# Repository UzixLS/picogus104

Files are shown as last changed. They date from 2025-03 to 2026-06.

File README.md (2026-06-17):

## PicoGUS/104
Gravis Ultrasound compatible sound card for IBM PC.

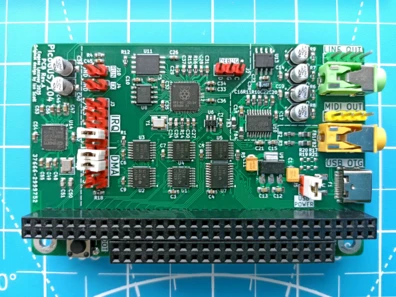
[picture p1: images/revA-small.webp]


This is variant of [PicoGUS](https://picog.us/) v2.0 project by [Ian Scott](https://ianscott.org/) adapted for PC/104 bus. This variant also integrates SAM2695 MIDI synthesizer on board.

For details and firmware please follow this link: https://github.com/polpo/picogus

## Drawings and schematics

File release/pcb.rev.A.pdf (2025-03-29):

220 | C19
IRQ | 42 GND 45 | VD³³ ⁴⁶ XDIV | 47 GND 48 VCM | 5 VA³³

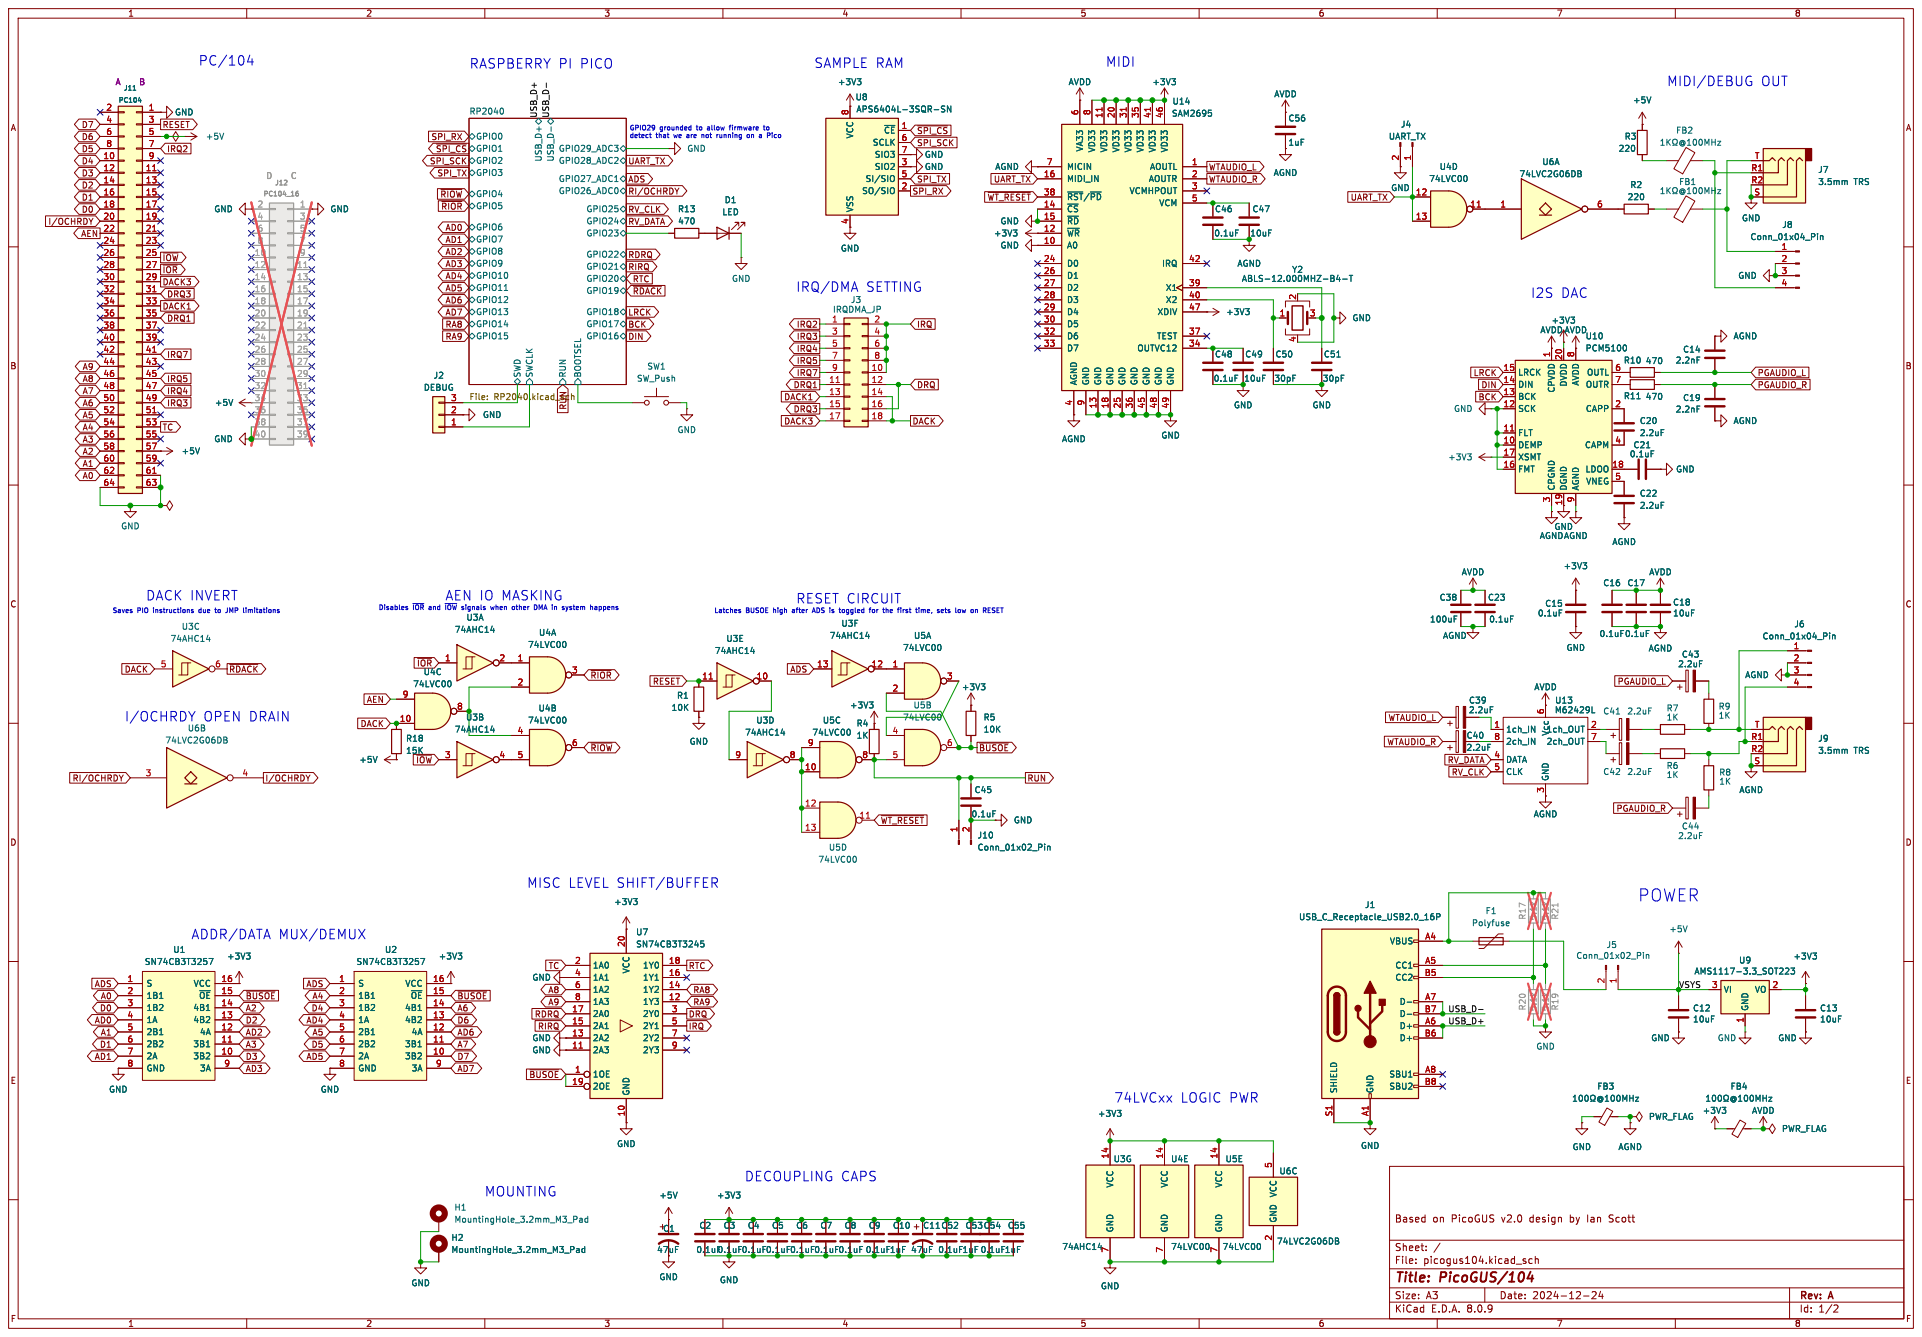
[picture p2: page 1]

4 SI/SIO 5 SCLK 6 SIO3 7 VCC
~{CE}1 SO/SIO 2 SIO2 3 VSS

1 DEMP 10 FLT 11 SCK 12 BCK 13 DIN 14

3 CAPM 4 VNEG 5 OUTL 6 OUTR 7 AVDD

MISC LEVEL SHIFT/BUFFER

ADDR/DATA MUX/DEMUX

100n C31

# 100n Raspberry Pi

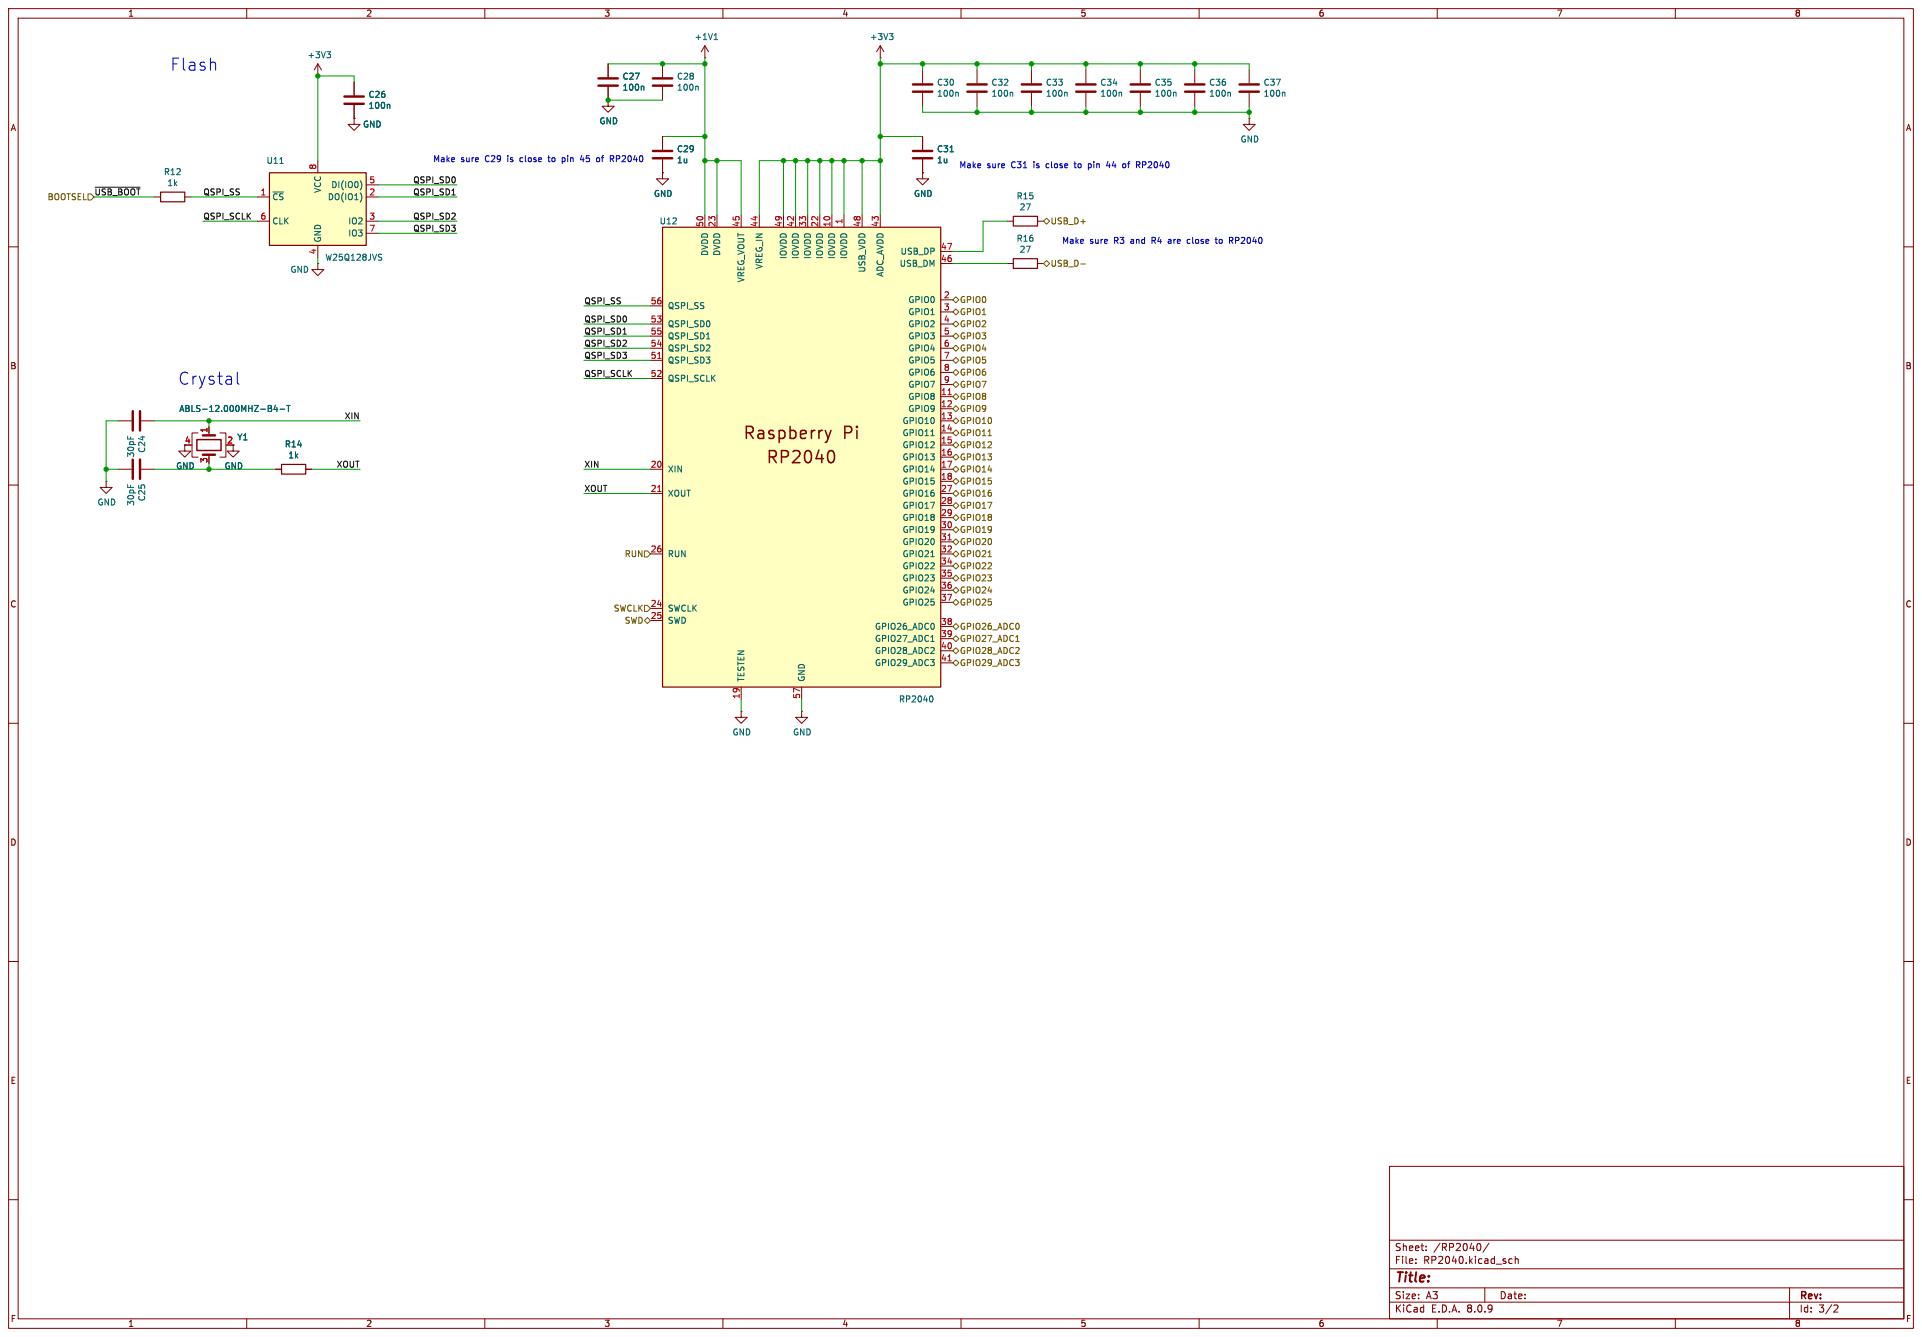
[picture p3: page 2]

1 IOVDD 10 GPIO8 11 GPIO9 12 GPIO10 13 GPIO11 14 GPIO12 15 GPIO13 16 GPIO14 17 GPIO15 18 TESTEN 19 GPIO0 2 XIN 20 XOUT 21 IOVDD 22 DVDD 23 SWCLK 24 SWD 25 RUN 26 GPIO16 27 GPIO17 28 GPIO18 29 GPIO1 3 GPIO19 30 GPIO20 31 GPIO21 32 IOVDD 33 GPIO22 34 GPIO23 35 GPIO24 36 GPIO25 37 GPIO26_ADC0 38 GPIO27_ADC1 39 GPIO2 4 GPIO28_ADC2 40 GPIO29_ADC3 41 IOVDD 42 ADC_AVDD 43 VREG_IN 44 VREG_VOUT 45 USB_DM 46 USB_DP 47 USB_VDD 48 IOVDD 49 GPIO3 5 DVDD 50 QSPI_SD3 51 QSPI_SCLK 52 QSPI_SD0 53 QSPI_SD2 54 QSPI_SD1 55 QSPI_SS 56 GND 57 GPIO4 6 GPIO5 7 GPIO6 8 GPIO7 9 U12 RP2040

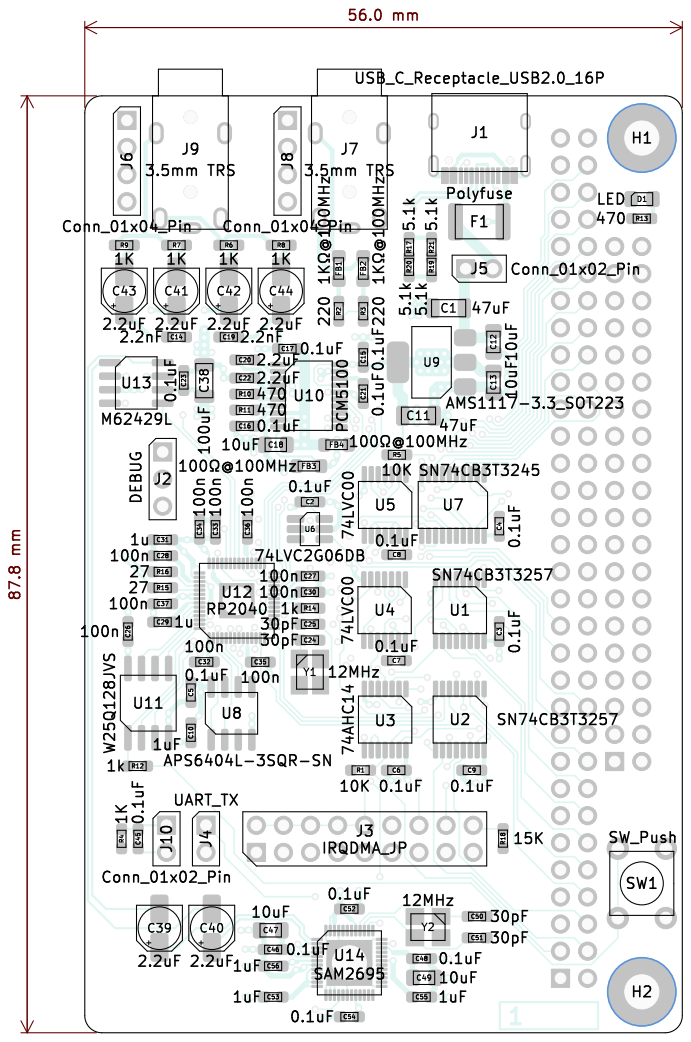
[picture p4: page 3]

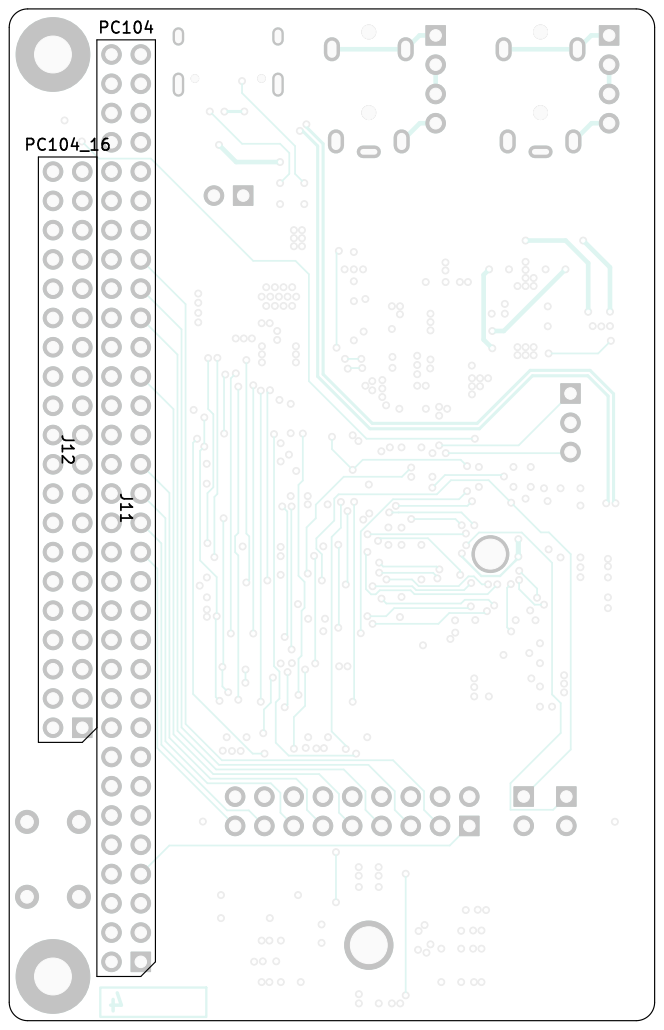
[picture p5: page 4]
D Date: 2024-12-24 KiCad; E.D.A. 8.0.9 Size: A4; Rev: A; File: picogus104.kicad_pcb Sheet: Eugene; Lozovoy Thickness: 1.6mm; Layers: 4 Dimensions:; Min; hole: 0.3mm; Min clearance:; Min track:

Min annular ring: 0.15mm

Id: 1/1 Title: PicoGUS/104

# Bill Of Materials

References | | | Value | Footprint | Qty
C1 C11 | 47uF | Capacitor_SMD:C_1206_3216Metric | 2
C2 C3 C4 C5 C6 C7 C8 C9 C15 C16 C17 C21 C23 C45 C46 C48 C52 C54 | 0.1uF | Capacitor_SMD:C_0603_1608Metric_Pad1.0 8x0.95mm_HandSolder | 18
C10 C53 C55 C56 | 1uF | Capacitor_SMD:C_0603_1608Metric_Pad1.0 8x0.95mm_HandSolder | 4
C12 C13 C18 C47 C49 | 10uF | Capacitor_SMD:C_0805_2012Metric_Pad1.1 8x1.45mm_HandSolder | 5
C14 C19 | 2.2nF | Capacitor_SMD:C_0603_1608Metric_Pad1.0 8x0.95mm_HandSolder | 2
C20 C22 | 2.2uF | Capacitor_SMD:C_0603_1608Metric_Pad1.0 8x0.95mm_HandSolder | 2
C38 | 100uF | Capacitor_SMD:C_1206_3216Metric | 1
C39 C40 C41 C42 C43 C44 | 2.2uF | Capacitor_SMD:CP_Elec_4x5.4 | 6
C50 C51 C24 C25 | 30pF | Capacitor_SMD:C_0603_1608Metric_Pad1.0 8x0.95mm_HandSolder | 4
D1 | LED | LED_SMD:LED_0805_2012Metric_Pad1.15x 1.40mm_HandSolder | 1
F1 | Polyfuse | Fuse:Fuse_1812_4532Metric_Pad1.30x3.40 mm_HandSolder | 1
FB1 FB2 | 1KΩ@100MHz | Inductor_SMD:L_0805_2012Metric_Pad1.05 x1.20mm_HandSolder | 2
FB3 FB4 | 100Ω@100MHz | Inductor_SMD:L_0805_2012Metric_Pad1.05 x1.20mm_HandSolder | 2
J1 | USB_C_Receptacle_USB2.0_16P | Connector_USB:USB_C_Receptacle_HRO_ TYPE-C-31-M-12 | 1
J3 | IRQDMA_JP | Connector_PinHeader_2.54mm:PinHeader_2 x09_P2.54mm_Vertical | 1
J6 J8 | Conn_01x04_Pin | Connector_PinHeader_2.54mm:PinHeader_1 x04_P2.54mm_Vertical | 2
J7 J9 | 3.5mm TRS | my:PJ-322 | 2
J11 | PC104 | Connector_PinHeader_2.54mm:PinHeader_2 x32_P2.54mm_Vertical | 1
R1 R5 | 10K | Resistor_SMD:R_0603_1608Metric_Pad0.98 x0.95mm_HandSolder | 2
R2 R3 | 220 | Resistor_SMD:R_0603_1608Metric_Pad0.98 x0.95mm_HandSolder | 2
R4 R6 R7 R8 R9 | 1K | Resistor_SMD:R_0603_1608Metric_Pad0.98 x0.95mm_HandSolder | 5
R10 R11 R13 | 470 | Resistor_SMD:R_0603_1608Metric_Pad0.98 x0.95mm_HandSolder | 3
R18 | 15K | Resistor_SMD:R_0603_1608Metric_Pad0.98 x0.95mm_HandSolder | 1
SW1 | SW_Push | Button_Switch_THT:SW_PUSH_6mm | 1
U1 U2 | SN74CB3T3257 | Package_SO:TSSOP-16_4.4x5mm_P0.65m m | 2
U3 | 74AHC14 | Package_SO:TSSOP-14_4.4x5mm_P0.65m m | 1

# picogus104 rev.A BOM page 1/2

U4 U5 | 74LVC00 | Package_SO:TSSOP-14_4.4x5mm_P0.65m m | 2
U6 | 74LVC2G06DB | Package_TO_SOT_SMD:SOT-23-6_Handsol dering | 1
U7 | SN74CB3T3245 | Package_SO:TSSOP-20_4.4x6.5mm_P0.65 mm | 1
U8 | APS6404L-3SQR-SN | Package_SO:SOIC-8_3.9x4.9mm_P1.27mm | 1
U9 | AMS1117-3.3_SOT223 | Package_TO_SOT_SMD:SOT-223-3_TabPin 2 | 1
U10 | PCM5100 | Package_SO:TSSOP-20_4.4x6.5mm_P0.65 mm | 1
U13 | M62429L | Package_SO:SOIC-8_3.9x4.9mm_P1.27mm | 1
U14 | SAM2695 | my:QFN-48-1EP_6x6mm_P0.4mm_EP4.2x4. 2mm | 1
Y2 Y1 | ABLS-12.000MHZ-B4-T | my:Crystal_SMD_3225-4Pin_3.2x2.5mm_Ha ndSoldering | 2
C26 C27 C28 C30 C32 C33 C34 C35 C36 C37 | 100n | Capacitor_SMD:C_0603_1608Metric_Pad1.0 8x0.95mm_HandSolder | 10
C29 C31 | 1u | Capacitor_SMD:C_0603_1608Metric_Pad1.0 8x0.95mm_HandSolder | 2
R12 R14 | 1k | Resistor_SMD:R_0603_1608Metric_Pad0.98 x0.95mm_HandSolder | 2
R15 R16 | 27 | Resistor_SMD:R_0603_1608Metric_Pad0.98 x0.95mm_HandSolder | 2
U11 | W25Q128JVS | my:SOIC-8_5.23x5.23mm_P1.27mm-LONG | 1
U12 | RP2040 | my:QFN-56-1EP_7x7mm_P0.4mm_EP3.2x3. 2mm | 1

# picogus104 rev.A BOM page 2/2

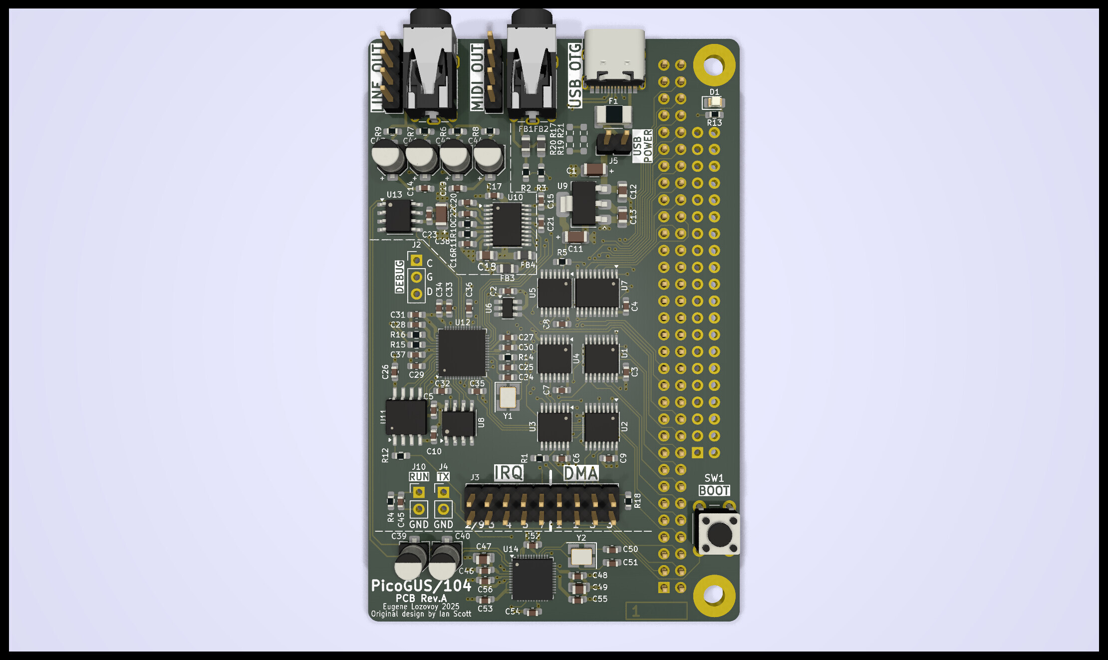
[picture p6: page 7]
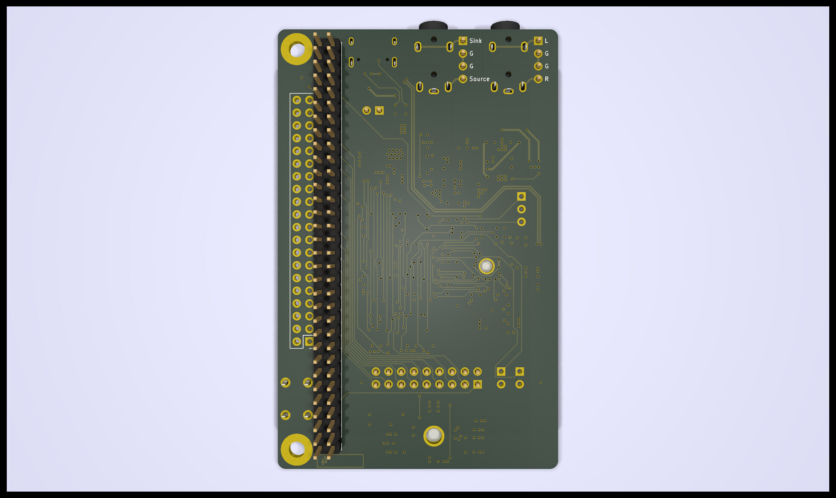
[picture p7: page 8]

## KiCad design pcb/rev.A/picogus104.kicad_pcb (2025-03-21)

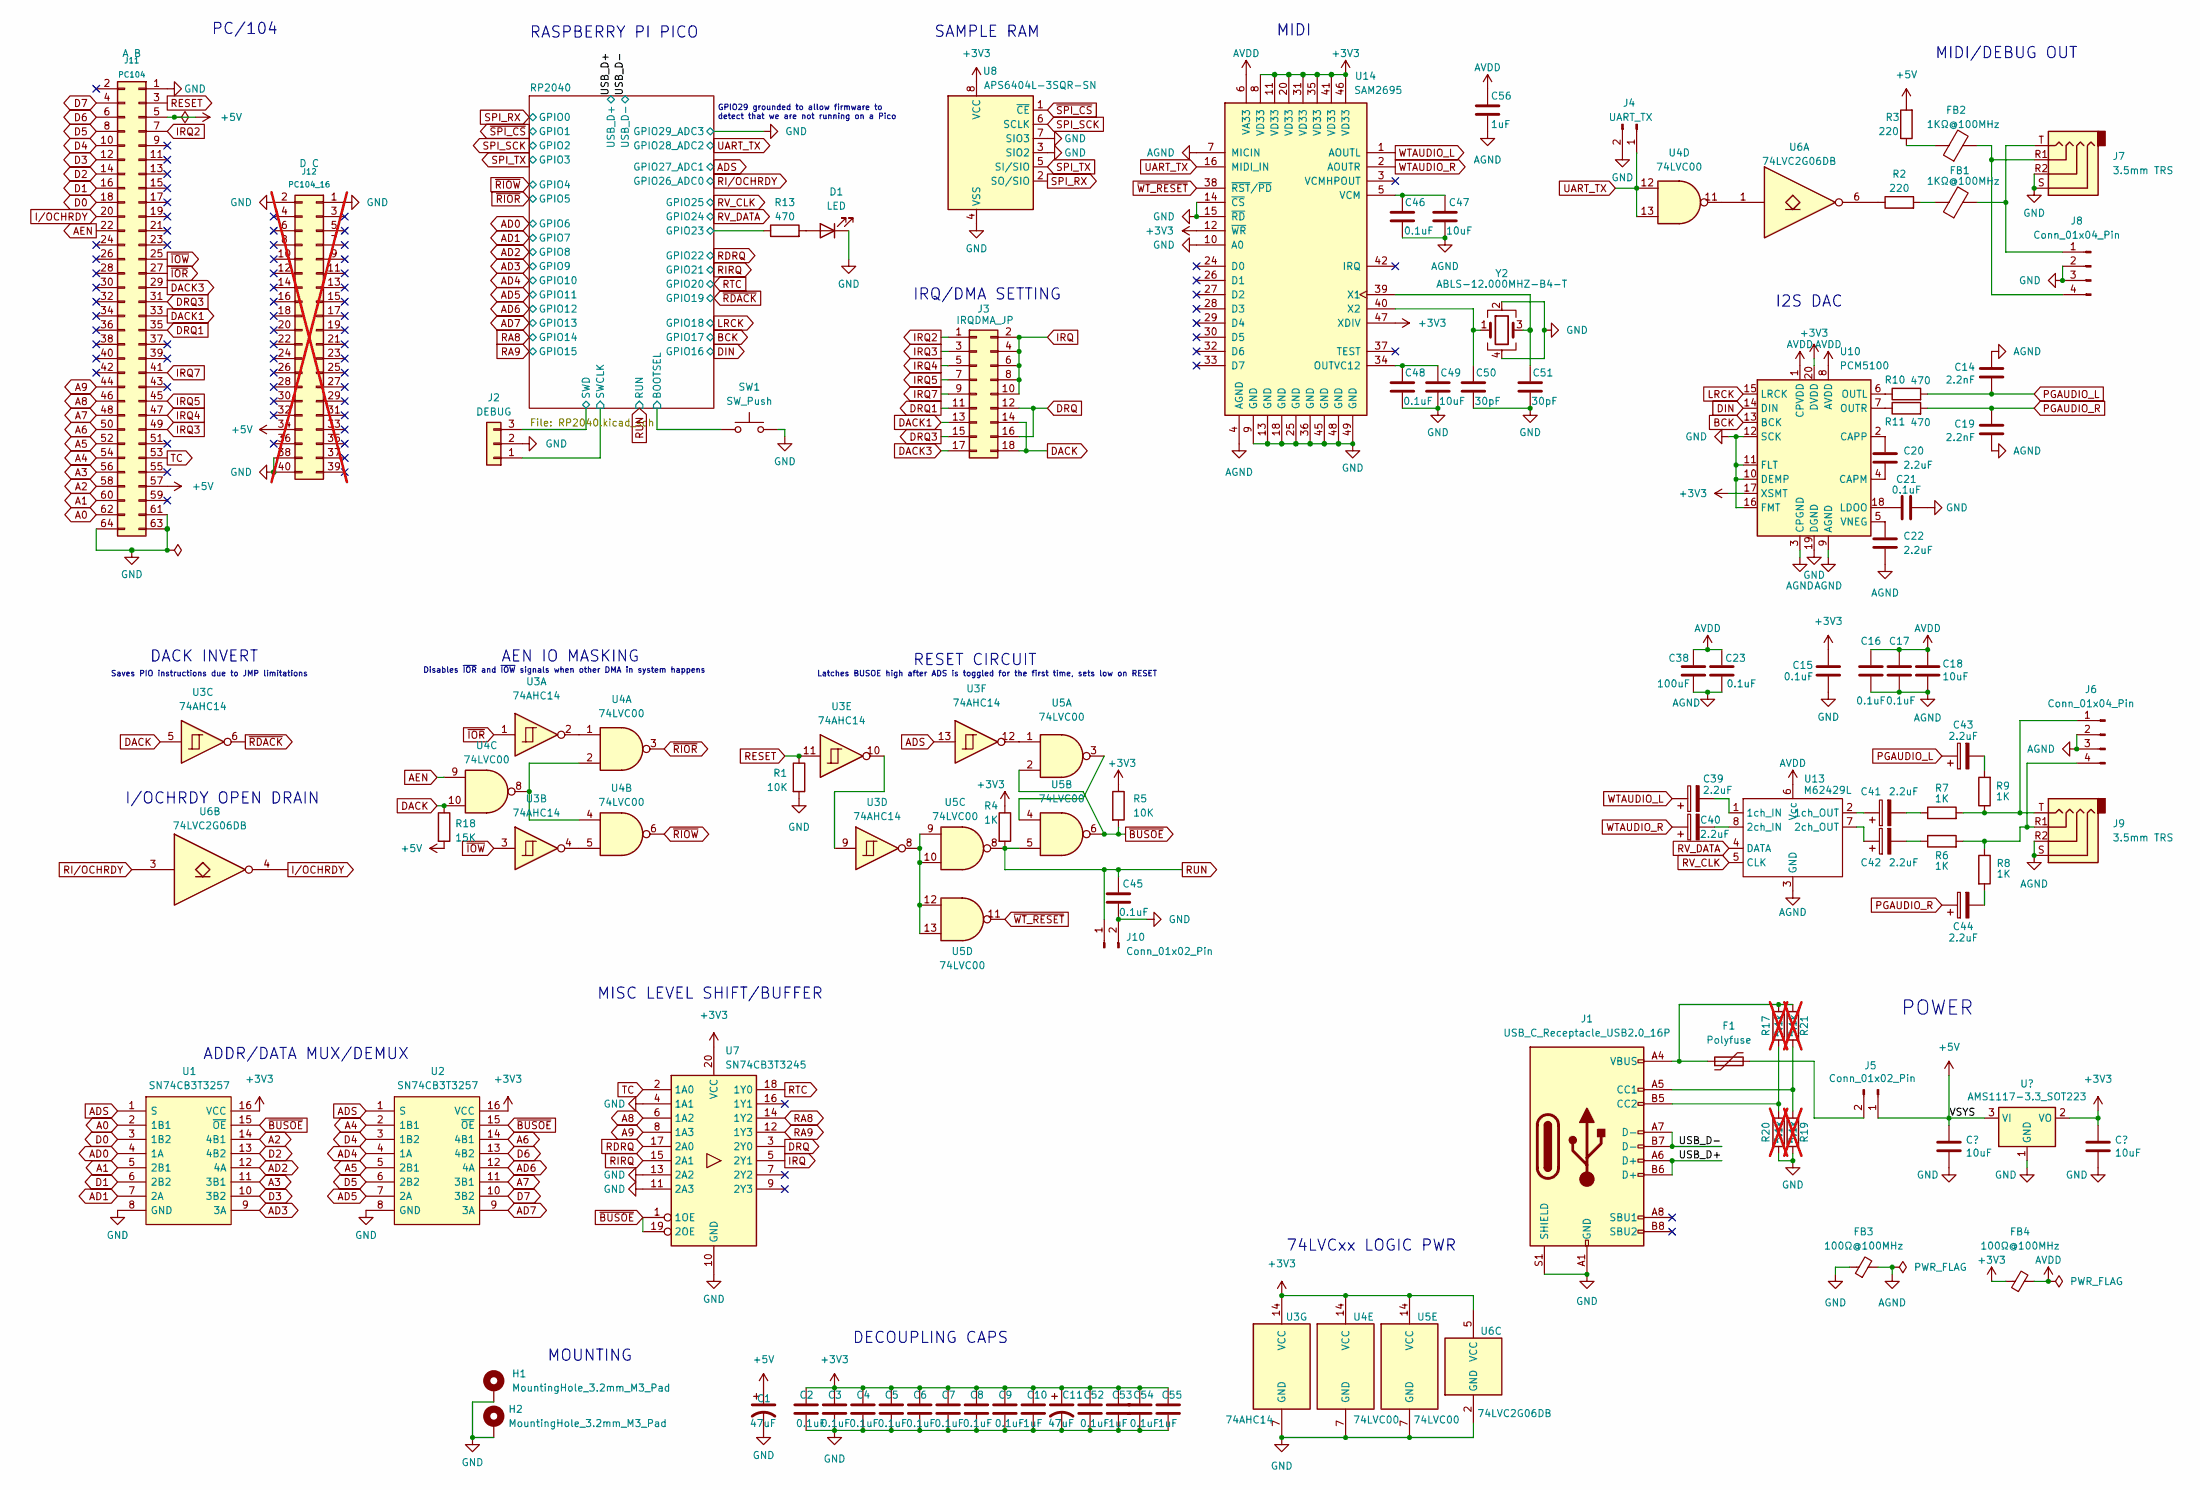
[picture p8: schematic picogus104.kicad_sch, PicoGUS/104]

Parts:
C1, C11: 47uF; C_1206_3216Metric
C2, C3, C4, C5, C6, C7, C8, C9, C15, C16, C17, C21, C23, C45, C46, C48, C52, C54: 0.1uF; C_0603_1608Metric_Pad1.08x0.95mm_HandSolder
C10, C53, C55, C56: 1uF; C_0603_1608Metric_Pad1.08x0.95mm_HandSolder
C12, C13, C18, C47, C49: 10uF; C_0805_2012Metric_Pad1.18x1.45mm_HandSolder
C14, C19: 2.2nF; C_0603_1608Metric_Pad1.08x0.95mm_HandSolder
C20, C22: 2.2uF; C_0603_1608Metric_Pad1.08x0.95mm_HandSolder
C38: 100uF; C_1206_3216Metric
C39, C40, C41, C42, C43, C44: 2.2uF; CP_Elec_4x5.4
C50, C51: 30pF; C_0603_1608Metric_Pad1.08x0.95mm_HandSolder
D1: LED; LED_0805_2012Metric_Pad1.15x1.40mm_HandSolder
F1: Polyfuse; Fuse_1812_4532Metric_Pad1.30x3.40mm_HandSolder
FB1, FB2: 1KΩ@100MHz; L_0805_2012Metric_Pad1.05x1.20mm_HandSolder
FB3, FB4: 100Ω@100MHz; L_0805_2012Metric_Pad1.05x1.20mm_HandSolder
H1, H2: MountingHole_3.2mm_M3_Pad
J1: USB_C_Receptacle_USB2.0_16P; USB_C_Receptacle_HRO_TYPE-C-31-M-12
J2: DEBUG; PinHeader_1x03_P2.54mm_Vertical
J3: IRQDMA_JP; PinHeader_2x09_P2.54mm_Vertical
J4: UART_TX; PinHeader_1x02_P2.54mm_Vertical
J5, J10: Conn_01x02_Pin; PinHeader_1x02_P2.54mm_Vertical
J6, J8: Conn_01x04_Pin; PinHeader_1x04_P2.54mm_Vertical
J7, J9: 3.5mm TRS; PJ-322
J11: PC104; PinHeader_2x32_P2.54mm_Vertical
J12: PC104_16; PinHeader_2x20_P2.54mm_Vertical; not fitted
R1, R5: 10K; R_0603_1608Metric_Pad0.98x0.95mm_HandSolder
R2, R3: 220; R_0603_1608Metric_Pad0.98x0.95mm_HandSolder
R4, R6, R7, R8, R9: 1K; R_0603_1608Metric_Pad0.98x0.95mm_HandSolder
R10, R11, R13: 470; R_0603_1608Metric_Pad0.98x0.95mm_HandSolder
R17, R19, R20, R21: 5.1k; R_0603_1608Metric_Pad0.98x0.95mm_HandSolder; not fitted
R18: 15K; R_0603_1608Metric_Pad0.98x0.95mm_HandSolder
SW1: SW_Push; SW_PUSH_6mm
U1, U2: SN74CB3T3257; TSSOP-16_4.4x5mm_P0.65mm; Manufacturer_Part_Number 74FST3257DR2G; Mouser Part Number 863-74FST3257DR2G
U3: 74AHC14; TSSOP-14_4.4x5mm_P0.65mm
U4, U5: 74LVC00; TSSOP-14_4.4x5mm_P0.65mm
U6: 74LVC2G06DB; SOT-23-6_Handsoldering
U7: SN74CB3T3245; TSSOP-20_4.4x6.5mm_P0.65mm
U8: APS6404L-3SQR-SN; SOIC-8_3.9x4.9mm_P1.27mm
U9: AMS1117-3.3_SOT223; SOT-223-3_TabPin2
U10: PCM5100; TSSOP-20_4.4x6.5mm_P0.65mm
U13: M62429L; SOIC-8_3.9x4.9mm_P1.27mm
U14: SAM2695; QFN-48-1EP_6x6mm_P0.4mm_EP4.2x4.2mm
Y2: ABLS-12.000MHZ-B4-T; Crystal_SMD_3225-4Pin_3.2x2.5mm_HandSoldering

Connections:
+3V3: C2.1, C3.1, C4.1, C5.1, C6.1, C7.1, C8.1, C9.1, C10.1, C11.1, C13.1, C15.2, C52.1, C53.1, C54.1, C55.1, FB4.1, R4.1, R5.1, U1.16 (VCC), U2.16 (VCC), U3.14 (VCC), U4.14 (VCC), U5.14 (VCC), U6.5 (VCC), U7.20 (VCC), U8.8 (VCC), U9.2 (VO), U10.17 (XSMT), U10.20 (DVDD), U14.8 (VD33), U14.11 (VD33), U14.12 (~WR), U14.20 (VD33), U14.31 (VD33), U14.35 (VD33), U14.41 (VD33), U14.46 (VD33), U14.47 (XDIV); also elsewhere on the board
+5V: C1.1, C12.1, J5.1, J11.5, J11.57, J12.34, R3.2, R18.2, U9.3 (VI)
/RP2040/GPIO23: R13.1; also elsewhere on the board
/RP2040/SWCLK: J2.1; also elsewhere on the board
/RP2040/SWD: J2.3; also elsewhere on the board
/RP2040/~USB_BOOT: SW1.2; also elsewhere on the board
/USB_D+: J1.A6 (D+), J1.B6 (D+); also elsewhere on the board
/USB_D-: J1.A7 (D-), J1.B7 (D-); also elsewhere on the board
A0: J11.62, U1.2 (1B1)
A1: J11.60, U1.5 (2B1)
A2: J11.58, U1.14 (4B1)
A3: J11.56, U1.11 (3B1)
A4: J11.54, U2.2 (1B1)
A5: J11.52, U2.5 (2B1)
A6: J11.50, U2.14 (4B1)
A7: J11.48, U2.11 (3B1)
A8: J11.46, U7.6 (1A2)
A9: J11.44, U7.8 (1A3)
AD0: U1.4 (1A); also elsewhere on the board
AD1: U1.7 (2A); also elsewhere on the board
AD2: U1.12 (4A); also elsewhere on the board
AD3: U1.9 (3A); also elsewhere on the board
AD4: U2.4 (1A); also elsewhere on the board
AD5: U2.7 (2A); also elsewhere on the board
AD6: U2.12 (4A); also elsewhere on the board
AD7: U2.9 (3A); also elsewhere on the board
ADS: U1.1 (S), U2.1 (S), U3.13; also elsewhere on the board
AEN: J11.22, U4.9
AGND: C14.1, C16.1, C17.1, C18.2, C19.1, C22.2, C23.2, C38.2, C46.1, C47.1, C56.2, FB3.2, J6.2, J6.3, J9.R2, J9.S, U10.3 (CPGND), U10.9 (AGND), U13.3 (GND), U14.4 (AGND), U14.7 (MICIN)
AVDD: C16.2, C17.2, C18.1, C23.1, C38.1, C56.1, FB4.2, U10.1 (CPVDD), U10.8 (AVDD), U13.6 (Vcc), U14.6 (VA33)
BCK: U10.13 (BCK); also elsewhere on the board
D0: J11.18, U1.3 (1B2)
D1: J11.16, U1.6 (2B2)
D2: J11.14, U1.13 (4B2)
D3: J11.12, U1.10 (3B2)
D4: J11.10, U2.3 (1B2)
D5: J11.8, U2.6 (2B2)
D6: J11.6, U2.13 (4B2)
D7: J11.4, U2.10 (3B2)
DACK: J3.14, J3.18, R18.1, U3.5, U4.10
DACK1: J3.13, J11.33
DACK3: J3.17, J11.29
DIN: U10.14 (DIN); also elsewhere on the board
DRQ: J3.12, J3.16, U7.3 (2Y0)
DRQ1: J3.11, J11.35
DRQ3: J3.15, J11.31
GND: C1.2, C2.2, C3.2, C4.2, C5.2, C6.2, C7.2, C8.2, C9.2, C10.2, C11.2, C12.2, C13.2, C15.1, C21.2, C45.2, C48.1, C49.1, C50.1, C51.1, C52.2, C53.2, C54.2, C55.2, D1.1 (K), FB3.1, H1.1, H2.1, J1.A1 (GND), J1.A12 (GND), J1.B1 (GND), J1.B12 (GND), J1.S1 (SHIELD), J2.2, J4.2, J7.R2, J7.S, J8.2, J8.3, J10.2, J11.1, J11.61, J11.63, J11.64, J12.1, J12.2, J12.38, J12.40, R1.2, R19.1, R20.1, SW1.1, U1.8 (GND), U2.8 (GND), U3.7 (GND), U4.7 (GND), U5.7 (GND), U6.2 (GND), U7.4 (1A1), U7.10 (GND), U7.11 (2A3), U7.13 (2A2), U8.3 (SIO2), U8.4 (VSS), U8.7 (SIO3), U9.1 (GND), U10.10 (DEMP), U10.11 (FLT), U10.12 (SCK), U10.16 (FMT), U10.19 (DGND), U14.9 (GND), U14.10 (A0), U14.13 (GND), U14.14 (~CS), U14.15 (~RD), U14.18 (GND), U14.25 (GND), U14.36 (GND), U14.45 (GND), U14.48 (GND), U14.49 (GND), Y2.2, Y2.4; also elsewhere on the board
IRQ: J3.2, J3.4, J3.6, J3.8, J3.10, U7.5 (2Y1)
IRQ2: J3.1, J11.7
IRQ3: J3.3, J11.49
IRQ4: J3.5, J11.47
IRQ5: J3.7, J11.45
IRQ7: J3.9, J11.41
I/OCHRDY: J11.20, U6.4
LRCK: U10.15 (LRCK); also elsewhere on the board
unnamed: C41.2, R7.1
unnamed: C42.2, R6.1
unnamed: C43.2, R9.2
unnamed: C44.2, R8.2
unnamed: D1.2 (A), R13.2
unnamed: F1.1, J1.A4 (VBUS), J1.A9 (VBUS), J1.B4 (VBUS), J1.B9 (VBUS), R17.2, R21.2
unnamed: FB1.1, R2.2
unnamed: FB2.1, R3.1
unnamed: J1.A5 (CC1), R19.2, R21.1
unnamed: J1.B5 (CC2), R17.1, R20.2
unnamed: F1.2, J5.2
unnamed: J6.1, J9.T, R7.2, R9.1
unnamed: J6.4, J9.R1, R6.2, R8.1
unnamed: FB1.2, J7.T, J8.1
unnamed: FB2.2, J7.R1, J8.4
unnamed: R2.1, U6.6
unnamed: U3.2, U4.1
unnamed: U3.4, U4.5
unnamed: U3.8, U5.9, U5.10, U5.12, U5.13
unnamed: U3.9, U3.10
unnamed: U3.12, U5.1
unnamed: U4.2, U4.4, U4.8
unnamed: U4.11, U6.1
unnamed: U5.3, U5.4
unnamed: C20.2, U10.4 (CAPM)
unnamed: C20.1, U10.2 (CAPP)
unnamed: C21.1, U10.18 (LDOO)
unnamed: R10.1, U10.6 (OUTL)
unnamed: R11.1, U10.7 (OUTR)
unnamed: C22.1, U10.5 (VNEG)
unnamed: C39.2, U13.1 (1ch_IN)
unnamed: C41.1, U13.2 (1ch_OUT)
unnamed: C40.2, U13.8 (2ch_IN)
unnamed: C42.1, U13.7 (2ch_OUT)
unnamed: C48.2, C49.2, U14.34 (OUTVC12)
unnamed: C46.2, C47.2, U14.5 (VCM)
unnamed: C51.2, U14.39 (X1), Y2.3
unnamed: C50.2, U14.40 (X2), Y2.1
PGAUDIO_L: C14.2, C43.1, R10.2
PGAUDIO_R: C19.2, C44.1, R11.2
RA8: U7.14 (1Y2); also elsewhere on the board
RA9: U7.12 (1Y3); also elsewhere on the board
RDRQ: U7.17 (2A0); also elsewhere on the board
RESET: J11.3, R1.1, U3.11
RIRQ: U7.15 (2A1); also elsewhere on the board
RI/OCHRDY: U6.3; also elsewhere on the board
RTC: U7.18 (1Y0); also elsewhere on the board
RUN: C45.1, J10.1, R4.2, U5.5, U5.8; also elsewhere on the board
RV_CLK: U13.5 (CLK); also elsewhere on the board
RV_DATA: U13.4 (DATA); also elsewhere on the board
SPI_RX: U8.2 (SO/SIO); also elsewhere on the board
SPI_SCK: U8.6 (SCLK); also elsewhere on the board
SPI_TX: U8.5 (SI/SIO); also elsewhere on the board
TC: J11.53, U7.2 (1A0)
UART_TX: J4.1, U4.12, U4.13, U14.16 (MIDI_IN); also elsewhere on the board
WTAUDIO_L: C39.1, U14.1 (AOUTL)
WTAUDIO_R: C40.1, U14.2 (AOUTR)
~BUSOE: R5.2, U1.15 (~OE), U2.15 (~OE), U5.2, U5.6, U7.1 (1OE), U7.19 (2OE)
~IOR: J11.27, U3.1
~IOW: J11.25, U3.3
~RDACK: U3.6; also elsewhere on the board
~RIOR: U4.3; also elsewhere on the board
~RIOW: U4.6; also elsewhere on the board
~SPI_CS: U8.1 (~CE); also elsewhere on the board
~WT_RESET: U5.11, U14.38 (~RST/~PD)

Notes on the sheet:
Saves PIO instructions due to JMP limitations
DECOUPLING CAPS
GPIO29 grounded to allow firmware to detect that we are not running on a Pico
I2S DAC
Disables ~{IOR} and ~{IOW} signals when other DMA in system happens
Latches BUSOE high after ADS is toggled for the first time, sets low on RESET
MIDI/DEBUG OUT
MOUNTING
MISC LEVEL SHIFT/BUFFER
IRQ/DMA SETTING
POWER
DACK INVERT
ADDR/DATA MUX/DEMUX
SAMPLE RAM
PC/104
AEN IO MASKING
RASPBERRY PI PICO
MIDI
RESET CIRCUIT
I/OCHRDY OPEN DRAIN
74LVCxx LOGIC PWR

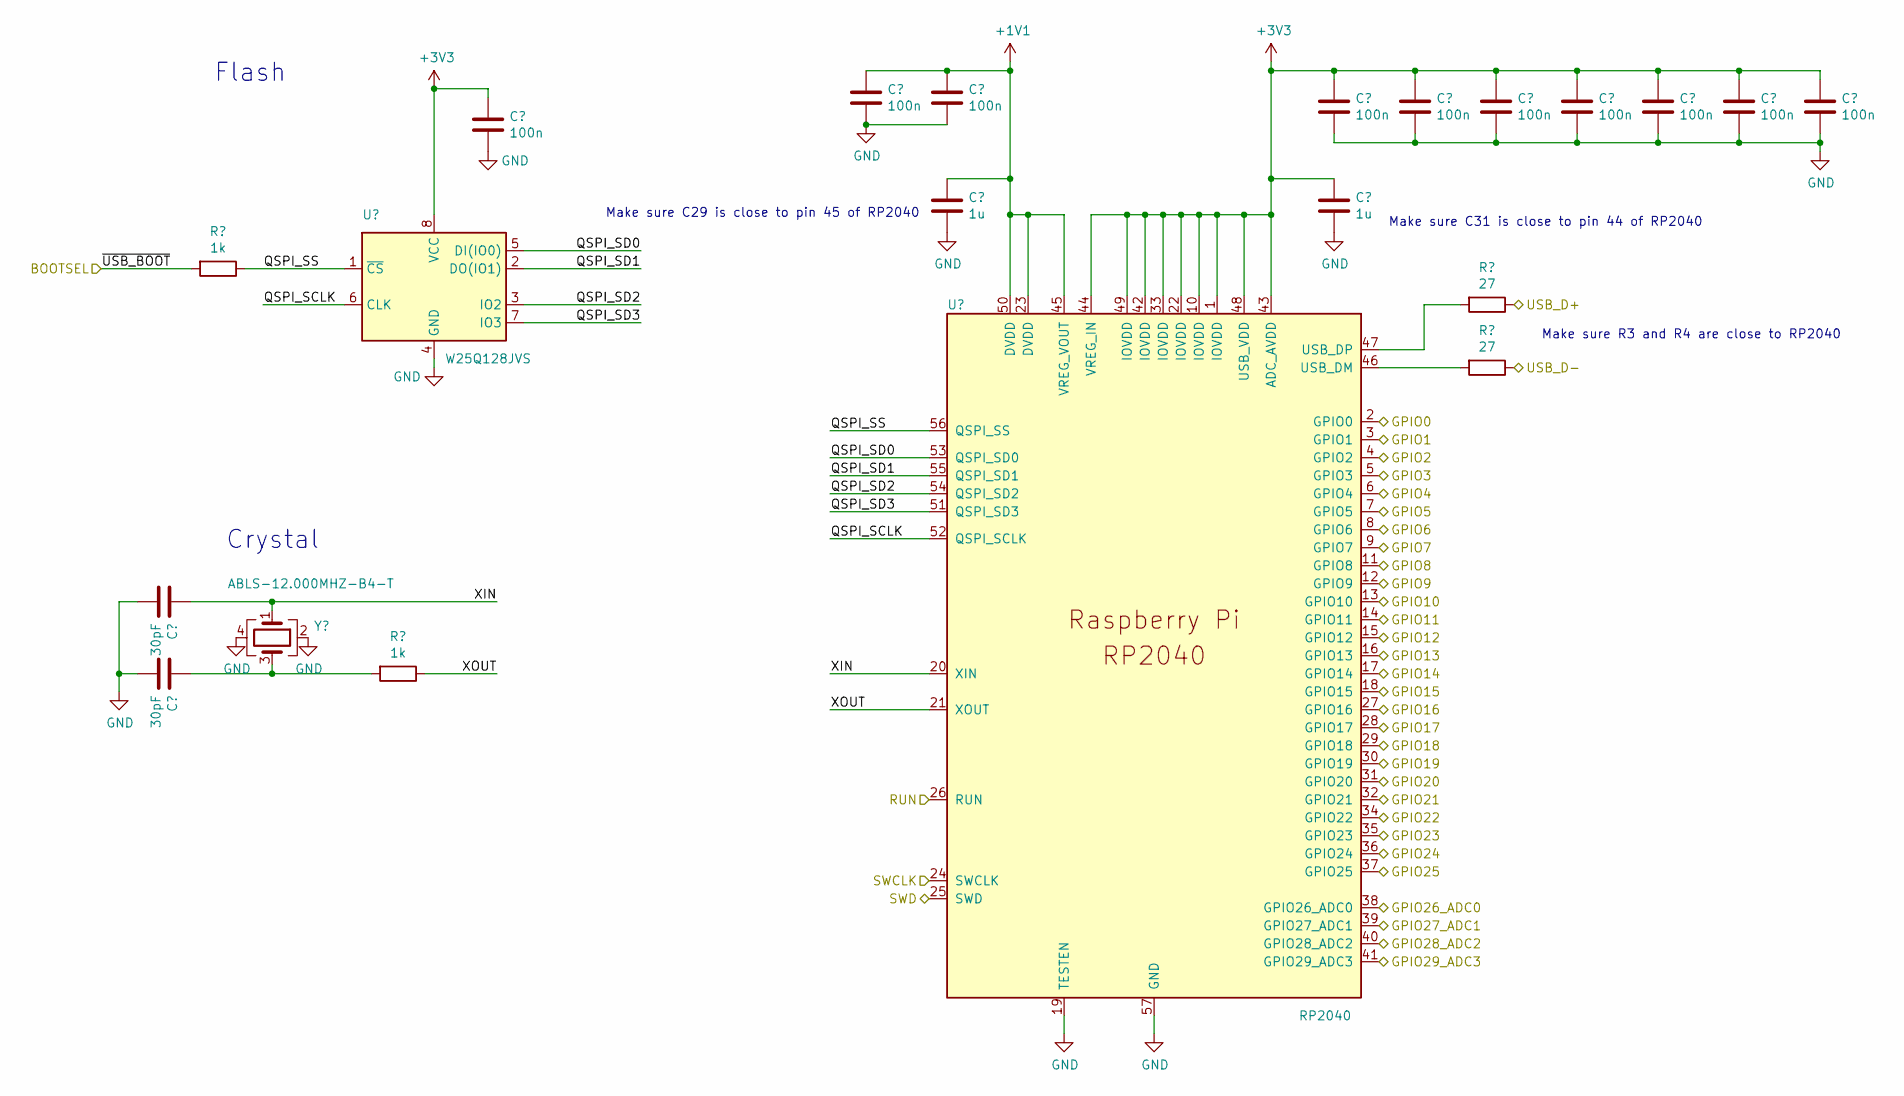
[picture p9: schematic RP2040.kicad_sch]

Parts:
C24, C25: 30pF; C_0603_1608Metric_Pad1.08x0.95mm_HandSolder
C26, C27, C28, C30, C32, C33, C34, C35, C36, C37: 100n; C_0603_1608Metric_Pad1.08x0.95mm_HandSolder
C29, C31: 1u; C_0603_1608Metric_Pad1.08x0.95mm_HandSolder
R12, R14: 1k; R_0603_1608Metric_Pad0.98x0.95mm_HandSolder
R15, R16: 27; R_0603_1608Metric_Pad0.98x0.95mm_HandSolder
U11: W25Q128JVS; SOIC-8_5.23x5.23mm_P1.27mm-LONG
U12: RP2040; QFN-56-1EP_7x7mm_P0.4mm_EP3.2x3.2mm
Y1: ABLS-12.000MHZ-B4-T; Crystal_SMD_3225-4Pin_3.2x2.5mm_HandSoldering

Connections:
+1V1: C27.1, C28.1, C29.1, U12.23 (DVDD), U12.45 (VREG_VOUT), U12.50 (DVDD)
+3V3: C26.1, C30.1, C31.1, C32.1, C33.1, C34.1, C35.1, C36.1, C37.1, U11.8 (VCC), U12.1 (IOVDD), U12.10 (IOVDD), U12.22 (IOVDD), U12.33 (IOVDD), U12.42 (IOVDD), U12.43 (ADC_AVDD), U12.44 (VREG_IN), U12.48 (USB_VDD), U12.49 (IOVDD); also elsewhere on the board
/RP2040/GPIO23: U12.35 (GPIO23); also elsewhere on the board
/RP2040/QSPI_SCLK: U11.6 (CLK), U12.52 (QSPI_SCLK)
/RP2040/QSPI_SD0: U11.5 (DI(IO0)), U12.53 (QSPI_SD0)
/RP2040/QSPI_SD1: U11.2 (DO(IO1)), U12.55 (QSPI_SD1)
/RP2040/QSPI_SD2: U11.3 (IO2), U12.54 (QSPI_SD2)
/RP2040/QSPI_SD3: U11.7 (IO3), U12.51 (QSPI_SD3)
/RP2040/QSPI_SS: R12.1, U11.1 (~CS), U12.56 (QSPI_SS)
/RP2040/SWCLK: U12.24 (SWCLK); also elsewhere on the board
/RP2040/SWD: U12.25 (SWD); also elsewhere on the board
/RP2040/XIN: C24.1, U12.20 (XIN), Y1.1
/RP2040/XOUT: R14.1, U12.21 (XOUT)
/RP2040/~USB_BOOT: R12.2; also elsewhere on the board
/USB_D+: R15.1; also elsewhere on the board
/USB_D-: R16.1; also elsewhere on the board
AD0: U12.8 (GPIO6); also elsewhere on the board
AD1: U12.9 (GPIO7); also elsewhere on the board
AD2: U12.11 (GPIO8); also elsewhere on the board
AD3: U12.12 (GPIO9); also elsewhere on the board
AD4: U12.13 (GPIO10); also elsewhere on the board
AD5: U12.14 (GPIO11); also elsewhere on the board
AD6: U12.15 (GPIO12); also elsewhere on the board
AD7: U12.16 (GPIO13); also elsewhere on the board
ADS: U12.39 (GPIO27_ADC1); also elsewhere on the board
BCK: U12.28 (GPIO17); also elsewhere on the board
DIN: U12.27 (GPIO16); also elsewhere on the board
GND: C24.2, C25.2, C26.2, C27.2, C28.2, C29.2, C30.2, C31.2, C32.2, C33.2, C34.2, C35.2, C36.2, C37.2, U11.4 (GND), U12.19 (TESTEN), U12.41 (GPIO29_ADC3), U12.57 (GND), Y1.2, Y1.4; also elsewhere on the board
LRCK: U12.29 (GPIO18); also elsewhere on the board
unnamed: C25.1, R14.2, Y1.3
unnamed: R16.2, U12.46 (USB_DM)
unnamed: R15.2, U12.47 (USB_DP)
RA8: U12.17 (GPIO14); also elsewhere on the board
RA9: U12.18 (GPIO15); also elsewhere on the board
RDRQ: U12.34 (GPIO22); also elsewhere on the board
RIRQ: U12.32 (GPIO21); also elsewhere on the board
RI/OCHRDY: U12.38 (GPIO26_ADC0); also elsewhere on the board
RTC: U12.31 (GPIO20); also elsewhere on the board
RUN: U12.26 (RUN); also elsewhere on the board
RV_CLK: U12.37 (GPIO25); also elsewhere on the board
RV_DATA: U12.36 (GPIO24); also elsewhere on the board
SPI_RX: U12.2 (GPIO0); also elsewhere on the board
SPI_SCK: U12.4 (GPIO2); also elsewhere on the board
SPI_TX: U12.5 (GPIO3); also elsewhere on the board
UART_TX: U12.40 (GPIO28_ADC2); also elsewhere on the board
~RDACK: U12.30 (GPIO19); also elsewhere on the board
~RIOR: U12.7 (GPIO5); also elsewhere on the board
~RIOW: U12.6 (GPIO4); also elsewhere on the board
~SPI_CS: U12.3 (GPIO1); also elsewhere on the board

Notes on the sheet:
Make sure R3 and R4 are close to RP2040
Make sure C29 is close to pin 45 of RP2040
Make sure C31 is close to pin 44 of RP2040
Flash
Crystal

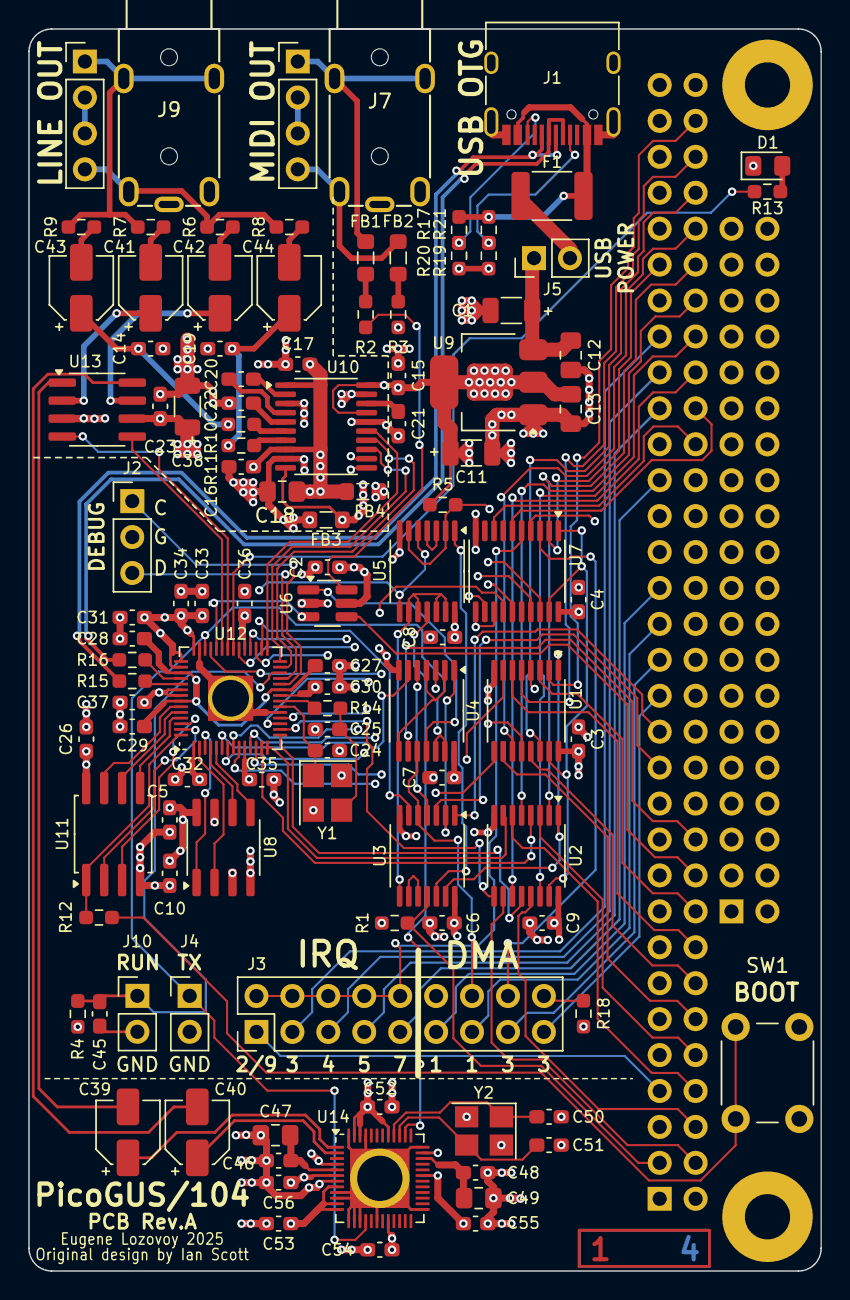
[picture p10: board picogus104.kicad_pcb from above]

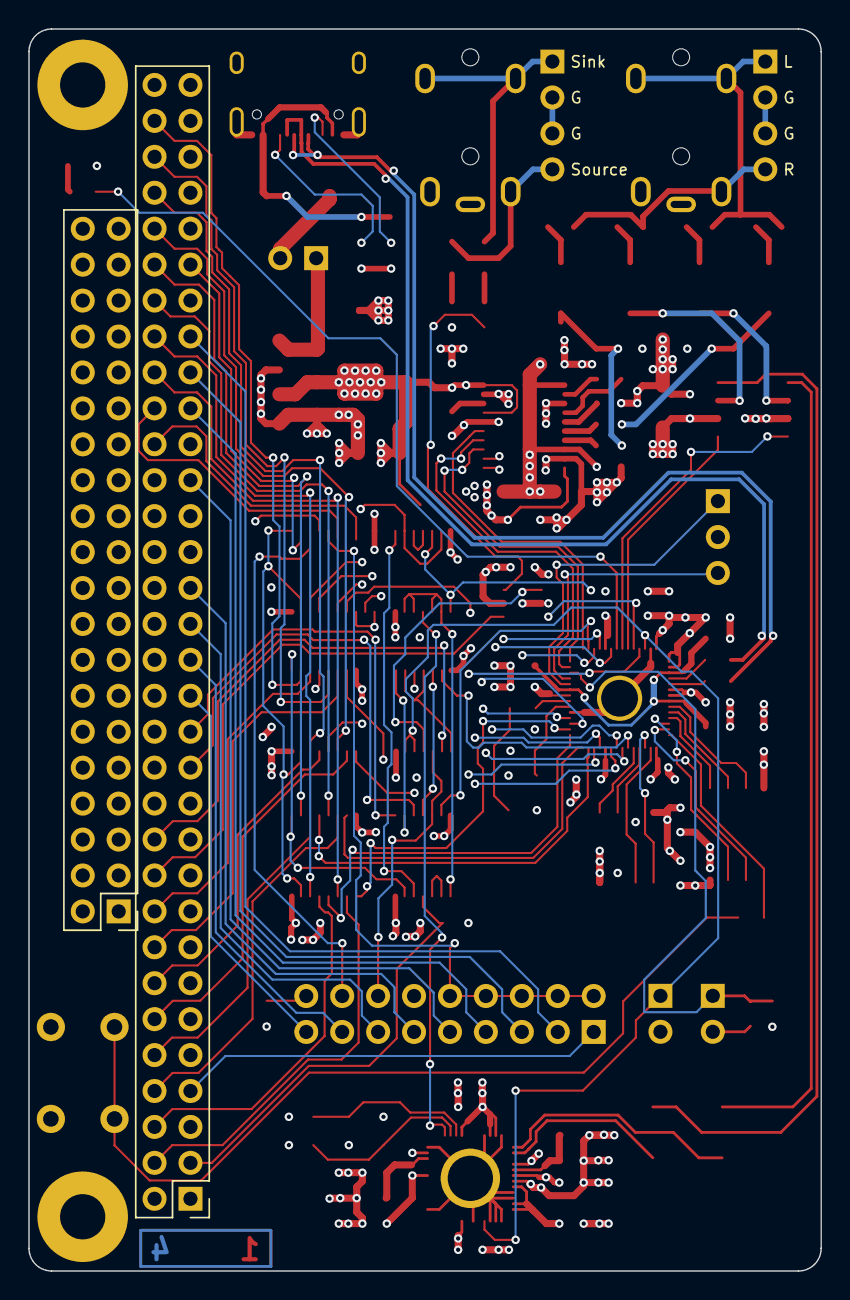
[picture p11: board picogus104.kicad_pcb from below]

Board: 4 copper layers, 56.0 x 87.8 mm, 114 parts (2 on the bottom side), 132 nets.

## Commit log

2024-12-24 wip pcb rev.A
    [RP2040.kicad_sch, picogus104.kicad_pcb, picogus104.kicad_sch]
2025-01-01 wip pcb reb.A - almost done
    [picogus104.kicad_pcb, picogus104.kicad_sch]
2025-03-19 pcb rev.A - final version
    [RP2040.kicad_sch, picogus104.kicad_pcb, picogus104.kicad_sch]
2025-03-21 bom fixes
    [picogus104.kicad_pcb, picogus104.kicad_sch]
2025-03-29 release pcb rev.A
